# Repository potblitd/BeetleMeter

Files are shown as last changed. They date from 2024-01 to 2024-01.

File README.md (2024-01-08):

<p align="center">
  
</p>

# BeetleMeter
Raising a beetle is fun and wholesome but keeping an eye on the environment inside the little fella's enclosure can be stressful and complicated. For this reason, the BeetleMeter is a tiny battery-powered PCB that instantly notifies the beetle keeper if the temperature and humidity is too high, too low or just right, by the push of a button.

## Circuitry
The SHT40 sensor is used to measure temperature (0.2 °C accuracy) and humidity (1.8 %RH accuracy), and communicate those values through I2C. The result can then be displayed through six LEDs i.e. temperature too high, too low or good, and humidity too high, too low, or good. In the first version, the system is controlled with the ATtiny85 and powered through a CR2032 coin cell (210mAh), while the second version uses the smaller ATtiny402 and is powered through two in series connected LR44 coin cells (150mAh). Due to the limited amount of GPIO pins of these two microcontrollers, the LEDs are switched through Charlieplexing. V1.0 incorporates the button signal on one of the remaining GPIOs and in V2.0 the button is used to power the system.

<p align="center">
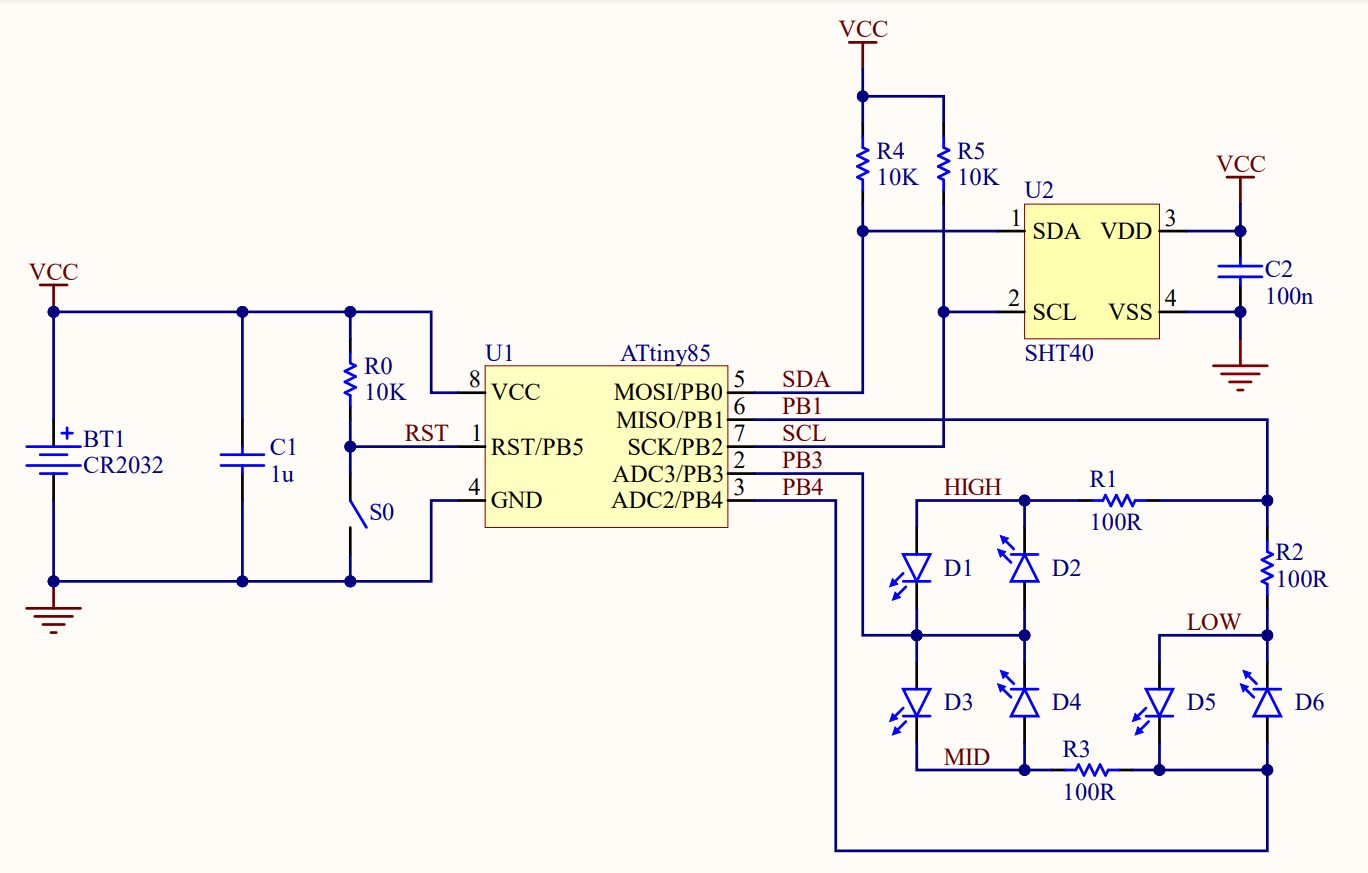
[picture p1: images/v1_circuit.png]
  
  &nbsp;&nbsp;&nbsp;&nbsp;&nbsp;
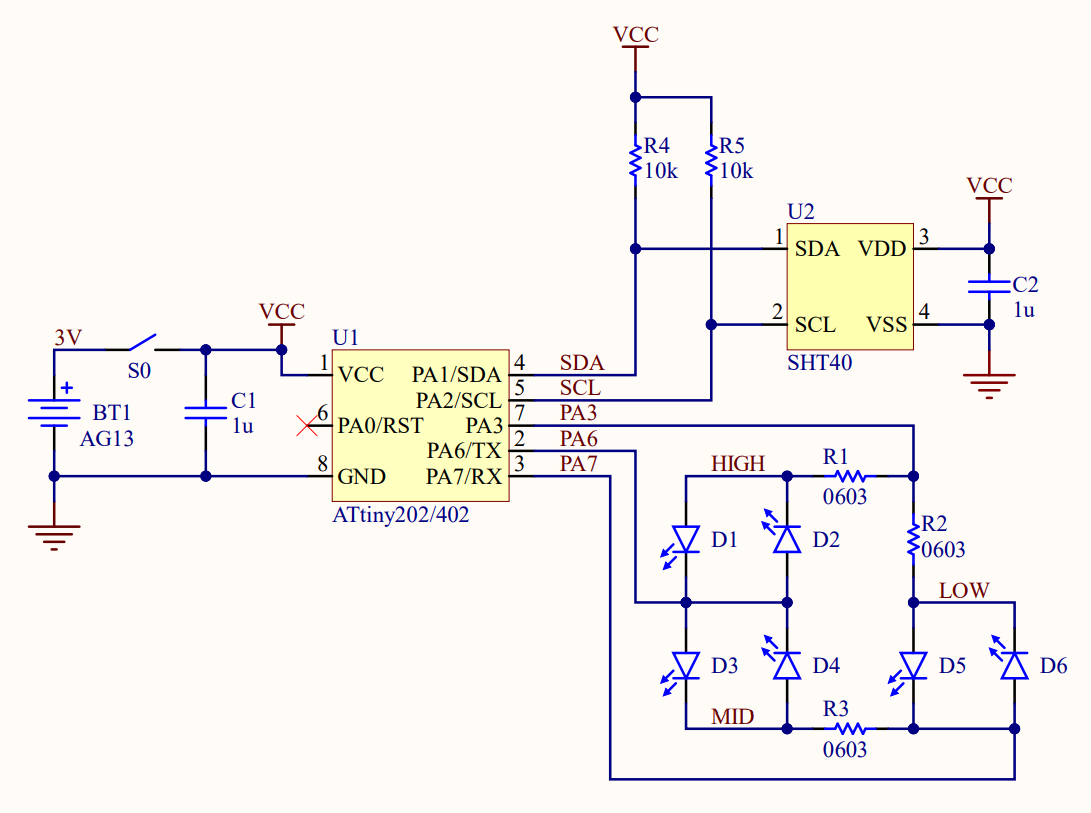
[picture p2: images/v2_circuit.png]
  
</p>

## PCB design
Both versions board outline is defined by the dimensions of their battery holder, which is mounted on the bottom side of the PCB. The top side accomodates the remaining components in SMD format. The push button size was also chosen according to the board space left.

<p align="center">
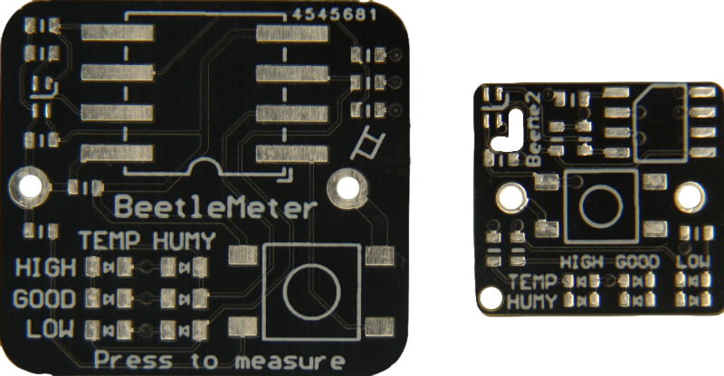
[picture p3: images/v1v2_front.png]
  
  &nbsp;&nbsp;&nbsp;&nbsp;&nbsp;
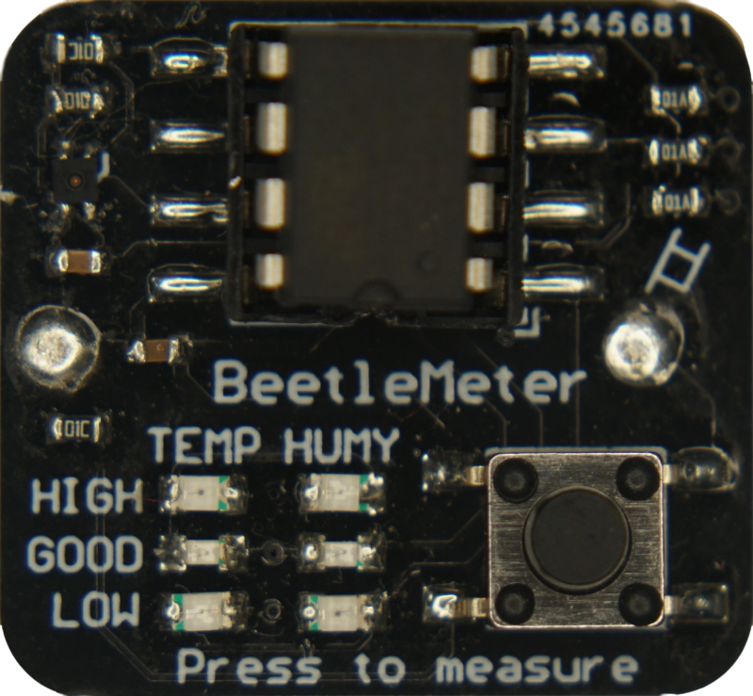
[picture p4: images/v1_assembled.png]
   
  &nbsp;&nbsp;&nbsp;&nbsp;&nbsp;
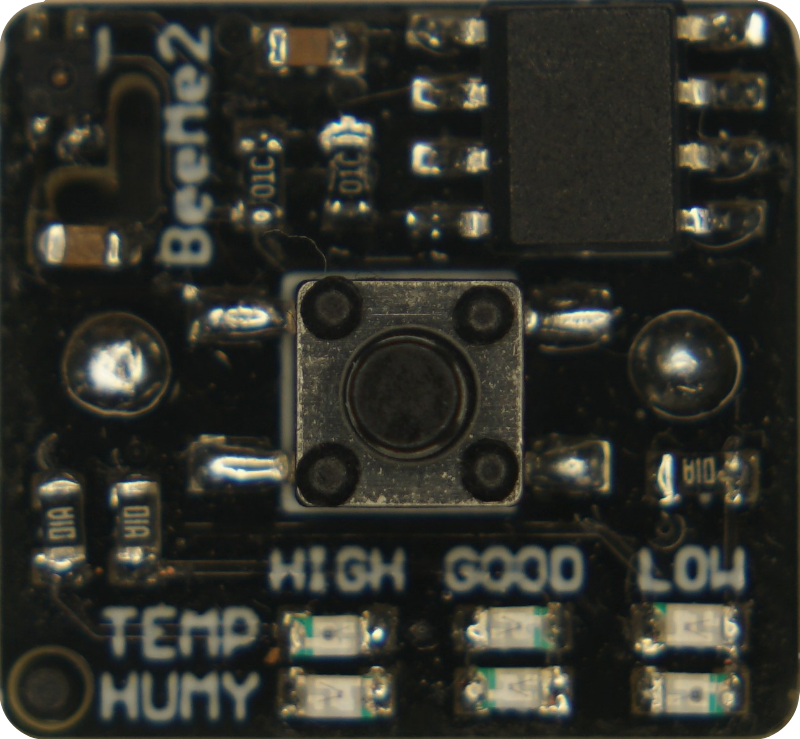
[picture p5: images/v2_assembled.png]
   <br/><br/>

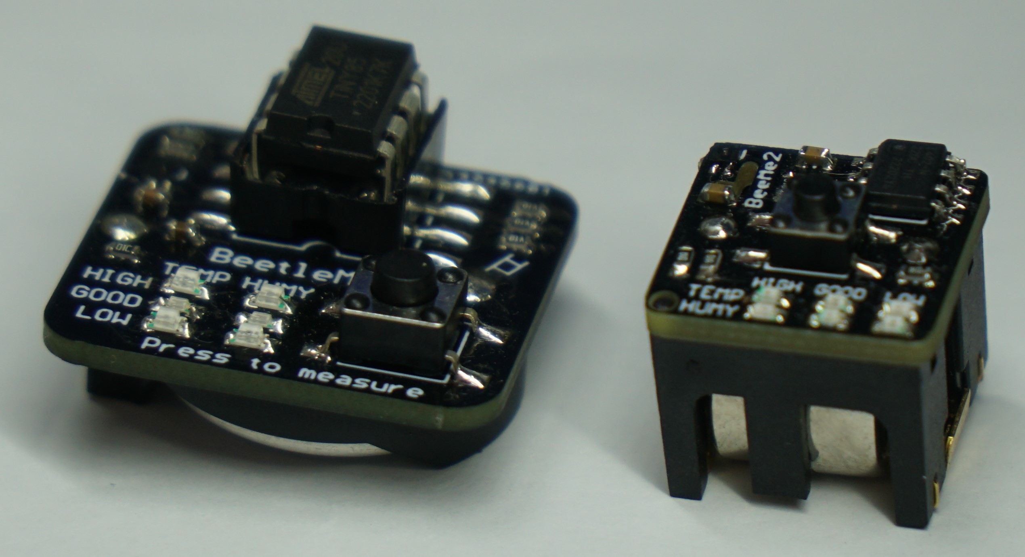
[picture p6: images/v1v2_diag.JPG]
   
</p>

## Code
[V1.0](code/BM-V1_measure-led-sleep/BM-V1_measure-led-sleep.ino) stays in sleep mode most of the time and only wakes up throug the button press after which the sensor is powered, measurements are read and the LEDs are turned ON for 1 second according to the suitable temperature and humidty range.

```ruby
void setup(){
  # get measurements
  if (sht.readSample()) {
    temp = sht.getTemperature();
    humy = sht.getHumidity();
  }

  # get temp and humy status
  if(temp > max_temp){
    temp_led = 2;
  } else if(temp < min_temp){
    temp_led = 5;
  } else {
    temp_led = 3;
  }
  if(humy > max_humy){
    humy_led = 1;
  } else if(humy < min_humy){
    humy_led = 6;
  } else {
    humy_led = 4;
  }

   # turn on LEDs
  for (int i = 0; i < ton/2; i ++) {
    setLED(temp_led);
    delay(1);
    setLED(humy_led);
    delay(1);
  }
}
  
  # sleep without wakeup
  sleepnowake();
```

[V2.0](code/BM-V2_measure-led/BM-V2_measure-led.ino) has basically the same code but without the need for a sleep mode since the system is not powered when the button is not pressed. Consequently, the LEDs stay turned ON until the button is released again.

```ruby
void setup(){
  # get measurements
  sht4x.measureHighPrecision(temp, humy);

  # get temp and humy status LEDs
  if(temp > max_temp){
    temp_led = 2;
  } else if(temp < min_temp){
    temp_led = 5;
  } else {
    temp_led = 3;
  }
  if(humy > max_humy){
    humy_led = 1;
  } else if(humy < min_humy){
    humy_led = 6;
  } else {
    humy_led = 4;
  }
}
void loop(){
  # turn on LEDs
  setLED(temp_led);
  delay(1);
  setLED(humy_led);
  delay(1);
}
```
## Cost
Total price for the components and batteries for V2 rounds up to 14 RMB (1.97 USD).

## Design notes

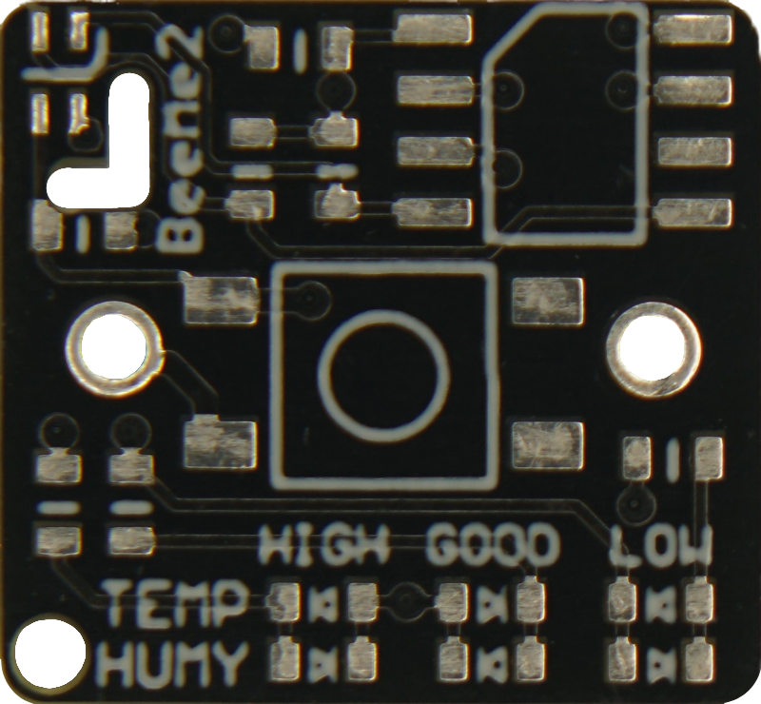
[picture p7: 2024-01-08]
images/v2_front.png

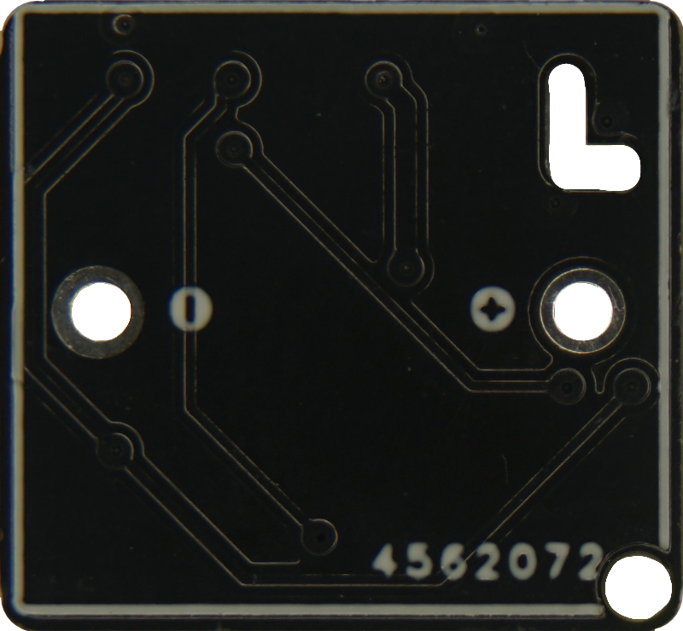
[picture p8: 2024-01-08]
images/v2_backj.png

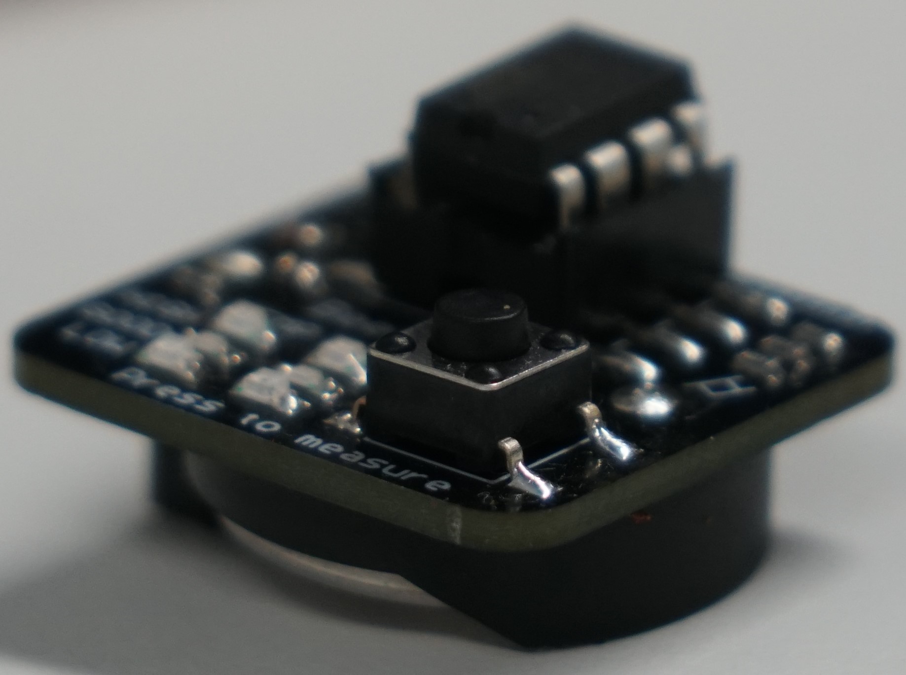
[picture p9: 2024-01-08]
images/v1_side.JPG

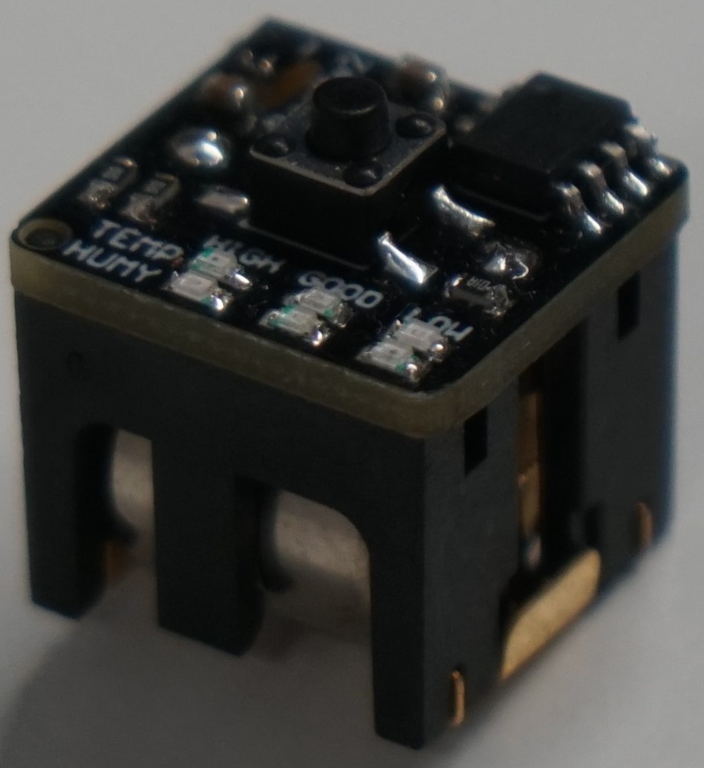
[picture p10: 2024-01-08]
images/v2_side.JPG

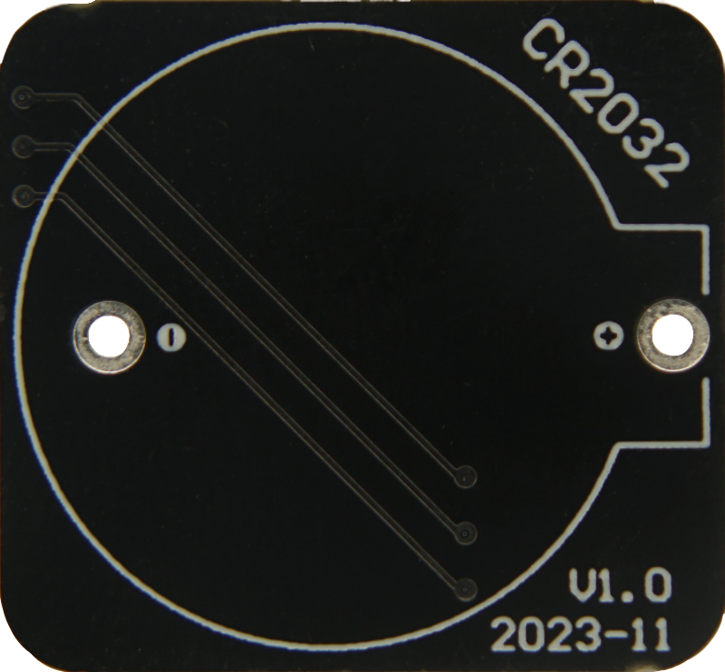
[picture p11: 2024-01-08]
images/v1_back.png

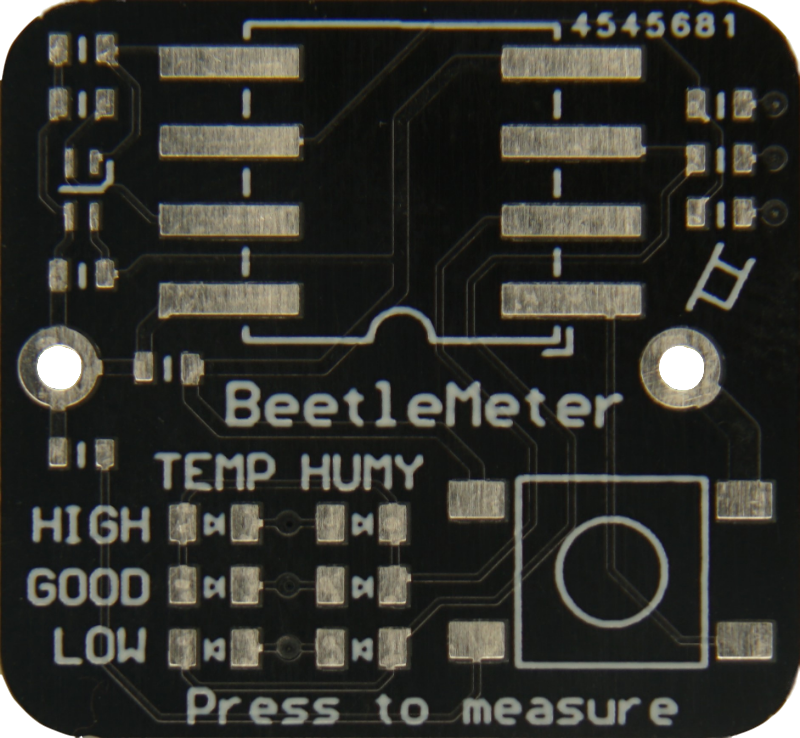
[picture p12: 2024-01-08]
images/v1_front.png

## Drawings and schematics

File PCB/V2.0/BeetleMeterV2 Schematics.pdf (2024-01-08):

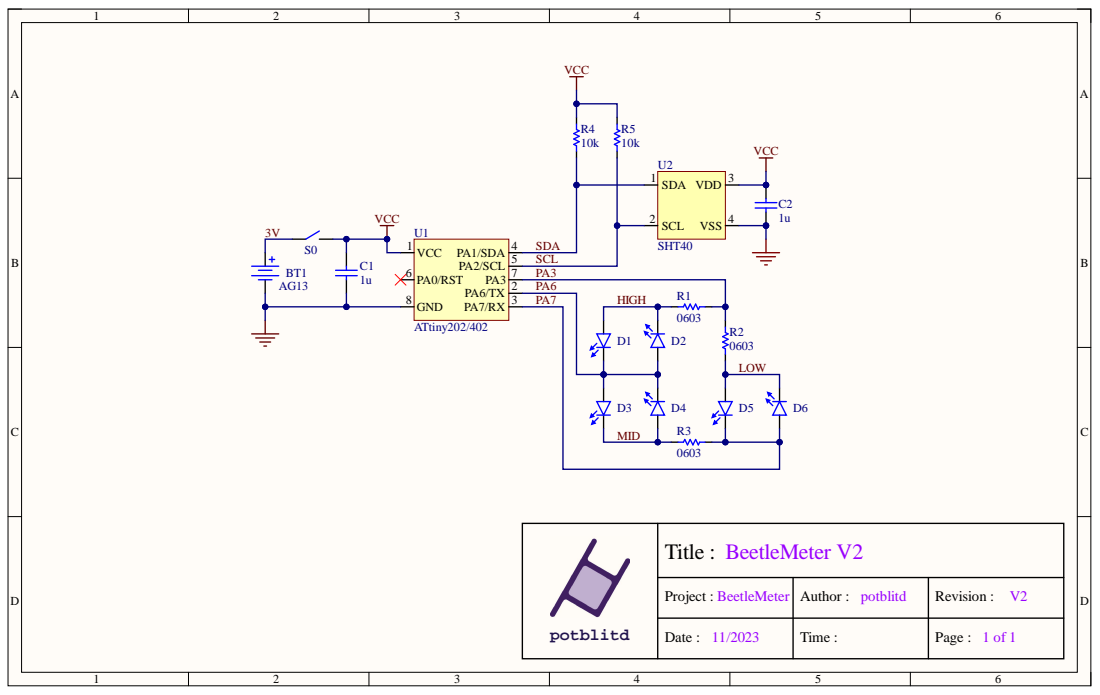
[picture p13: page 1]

potblitd | Titl e : Be etl eMeter V2

Project : BeetleMete r | Auth or : p otb l itd | Rev isi o n : 1V 2

Date : 1 1/2 0 2 3 | Time : | Page : 1 o f

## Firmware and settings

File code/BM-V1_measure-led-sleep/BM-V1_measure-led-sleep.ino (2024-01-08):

// BeetleMeter1.0 with ATtiny85
// ---------- PARAMETER SETTING ---------- \\
// LED shining time in milliseoncds
const byte ton = 1000;
// LED numbering
byte temp_led = 0;
byte humy_led = 0;
// measurement ranges
const byte max_temp = 25;
const byte min_temp = 12;
const byte max_humy = 70;
const byte min_humy = 50;

// import sleep library
#include <avr/sleep.h>
#include <SHTSensor.h>
#include <Wire.h>

// create sensor object
SHTSensor sht;
// init measure variables
float temp = 0;
float humy = 0;

// ---------- LED FUNCTION ---------- \\
// function to turn ON a single LED (and turn OFF all the other ones)
// this part should not be changes, it is related to the hardware
void setLED(byte ledNum){
  if(ledNum == 0){
    // All LEDs OFF
    DDRB &= ~(1 << PB1);
    DDRB &= ~(1 << PB3);
    DDRB &= ~(1 << PB4);
  }
  if(ledNum == 1){
    // PB1 -> PB3
    DDRB |= (1 << PB1);
    DDRB |= (1 << PB3);
    DDRB &= ~(1 << PB4);
    PORTB |= (1 << PB1);            
    PORTB &= ~(1 << PB3);
  }
  if(ledNum == 2){
    // PB3 -> PB1
    DDRB |= (1 << PB1);
    DDRB |= (1 << PB3);
    DDRB &= ~(1 << PB4);
    PORTB |= (1 << PB3);            
    PORTB &= ~(1 << PB1);
  }
  if(ledNum == 3){
    // PB3 -> PB4
    DDRB |= (1 << PB3);
    DDRB |= (1 << PB4);
    DDRB &= ~(1 << PB1);
    PORTB |= (1 << PB3);            
    PORTB &= ~(1 << PB4);
  }
  if(ledNum == 4){
    // PB4 -> PB3
    DDRB |= (1 << PB3);
    DDRB |= (1 << PB4);
    DDRB &= ~(1 << PB1);
    PORTB |= (1 << PB4);            
    PORTB &= ~(1 << PB3);
  }
  if(ledNum == 5){
    // PB1 -> PB4
    DDRB |= (1 << PB1);
    DDRB |= (1 << PB4);
    DDRB &= ~(1 << PB3);
    PORTB |= (1 << PB1);            
    PORTB &= ~(1 << PB4);
  }
  if(ledNum == 6){
    // PB1 -> PB4
    DDRB |= (1 << PB1);
    DDRB |= (1 << PB4);
    DDRB &= ~(1 << PB3);
    PORTB |= (1 << PB4);            
    PORTB &= ~(1 << PB1);
  }
}

// ---------- SLEEP FUNCTION ---------- \\
// sleep function
void sleepnowake(void){
  // turn off all LEDs
  pinMode(0, INPUT_PULLUP);
  pinMode(1, INPUT_PULLUP);
  pinMode(2, INPUT_PULLUP);
  pinMode(3, INPUT_PULLUP);
  pinMode(4, INPUT_PULLUP);
  // set sleep mode
  set_sleep_mode(SLEEP_MODE_PWR_DOWN);
  // go to sleep
  sleep_enable();
  sleep_cpu();
}

// ---------- SETUP CODE ---------- \\
// the code below is performed only once at the beginning before the main loop
void setup(){
  // all LEDs OFF
  setLED(0);
  // disable ADC
  ADCSRA &= ~(1<<ADEN);

  // init wire
  Wire.begin();
  // init sensor
  sht.init();
  // get measurements
  if (sht.readSample()) {
    temp = sht.getTemperature();
    humy = sht.getHumidity();
  }
  if(humy > 100){
    humy = 100;
  } else if(humy < 0){
    humy = 0;
  }

  // get temp and humy status
  if(temp > max_temp){
    temp_led = 2;
  } else if(temp < min_temp){
    temp_led = 5;
  } else {
    temp_led = 3;
  }
  if(humy > max_humy){
    humy_led = 1;
  } else if(humy < min_humy){
    humy_led = 6;
  } else {
    humy_led = 4;
  }

  // turn on LEDs
  for (int i = 0; i < ton/2; i ++) {
    setLED(temp_led);
    delay(1);
    setLED(humy_led);
    delay(1);
  }
  
  // sleep without wakeup
  sleepnowake();
}

// ---------- MAIN LOOP ---------- \\
// once the programm enters this loop, it repeats indefinitly until power-off or reset 
void loop(){
  
}

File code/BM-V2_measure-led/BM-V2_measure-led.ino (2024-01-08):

// BeetleMeter2.0 with ATtiny402
// ---------- PARAMETER SETTING ----------
// measurement ranges
const byte max_temp = 30;
const byte min_temp = 15;
const byte max_humy = 80;
const byte min_humy = 40;

// include ATtiny I2C library
#include <Wire.h>
#include <SensirionI2CSht4x.h>
// init sensor
SensirionI2CSht4x sht4x;

// init measure variables
float temp = 0;
float humy = 0;
// init LEDs
byte temp_led = 0;
byte humy_led = 0;

// ---------- LED FUNCTION ----------
void setLED(byte ledNum){
  if(ledNum == 0){
    // All LEDs OFF
    PORTA.DIRCLR = PIN3_bm;
    PORTA.DIRCLR = PIN6_bm;
    PORTA.DIRCLR = PIN7_bm;
  }
  if(ledNum == 1){
    // PA3 -> PA6
    PORTA.DIR = PIN3_bm | PIN6_bm;
    PORTA.DIRCLR = PIN7_bm;
    PORTA.OUTSET = PIN3_bm;           
    PORTA.OUTCLR = PIN6_bm;
  }
  if(ledNum == 2){
    // PA6 -> PA3
    PORTA.DIR = PIN3_bm | PIN6_bm;
    PORTA.DIRCLR = PIN7_bm;
    PORTA.OUTSET = PIN6_bm;           
    PORTA.OUTCLR = PIN3_bm;
  }
  if(ledNum == 3){
    // PA6 -> PA7
    PORTA.DIR = PIN6_bm | PIN7_bm;
    PORTA.DIRCLR = PIN3_bm;
    PORTA.OUTSET = PIN6_bm;           
    PORTA.OUTCLR = PIN7_bm;
  }
  if(ledNum == 4){
    // PA7 -> PA6
    PORTA.DIR = PIN6_bm | PIN7_bm;
    PORTA.DIRCLR = PIN3_bm;
    PORTA.OUTSET = PIN7_bm;           
    PORTA.OUTCLR = PIN6_bm;
  }
  if(ledNum == 5){
    // PA3 -> PA7
    PORTA.DIR = PIN3_bm | PIN7_bm;
    PORTA.DIRCLR = PIN6_bm;
    PORTA.OUTSET = PIN3_bm;           
    PORTA.OUTCLR = PIN7_bm;
  }
  if(ledNum == 6){
    // PA7 -> PA3
    PORTA.DIR = PIN3_bm | PIN7_bm;
    PORTA.DIRCLR = PIN6_bm;
    PORTA.OUTSET = PIN7_bm;           
    PORTA.OUTCLR = PIN3_bm;
  }
}

// ---------- SETUP CODE ---------- 
void setup(){
  // all LEDs OFF
  setLED(0);

  // init wire
  Wire.begin();
  // init SHT40 with high res measurement and measure
  sht4x.begin(Wire);
  sht4x.measureHighPrecision(temp, humy);

  // get temp and humy status LEDs
  if(temp > max_temp){
    temp_led = 2;
  } else if(temp < min_temp){
    temp_led = 5;
  } else {
    temp_led = 3;
  }
  if(humy > max_humy){
    humy_led = 1;
  } else if(humy < min_humy){
    humy_led = 6;
  } else {
    humy_led = 4;
  }
}

// ---------- MAIN LOOP ---------- 
void loop(){
  // turn on LEDs
  setLED(temp_led);
  delay(1);
  setLED(humy_led);
  delay(1);
  
}
